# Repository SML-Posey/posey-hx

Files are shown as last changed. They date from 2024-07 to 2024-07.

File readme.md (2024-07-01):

# Posey Hub Platform

This is a simple IMU hardware platform sized to fit in a waist-mounted device. The hub unit operates as both an IMU and a data collection device, connecting to other Posey devices and logging their data to on-board flash.

It includes:

- nRF5340 ARM microtroller with BLE radio
- CEVA BNO086 9-axis IMU
- Flash
- Lithium-polymer operation and charging

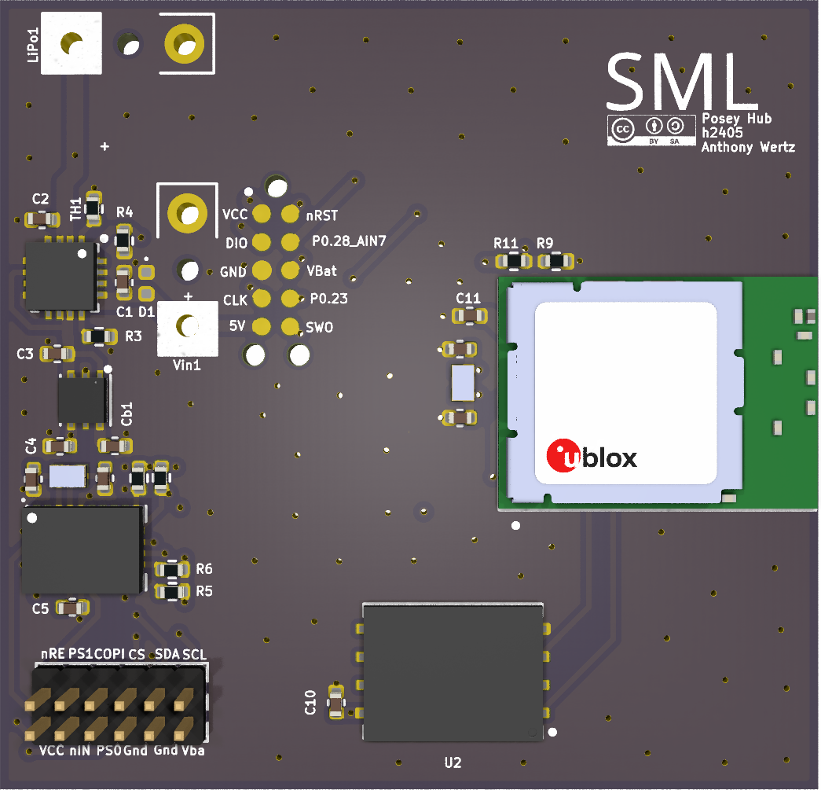
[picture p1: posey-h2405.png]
CAD rendering


## Author

[Anthony Wertz](https://me.anthonywertz.com)

## License

Shield: [][cc-by-sa]

This work is licensed under a
[Creative Commons Attribution-ShareAlike 4.0 International License][cc-by-sa].

[][cc-by-sa]

[cc-by-sa]: http://creativecommons.org/licenses/by-sa/4.0/
[cc-by-sa-image]: https://licensebuttons.net/l/by-sa/4.0/88x31.png
[cc-by-sa-shield]: https://img.shields.io/badge/License-CC%20BY--SA%204.0-lightgrey.svg

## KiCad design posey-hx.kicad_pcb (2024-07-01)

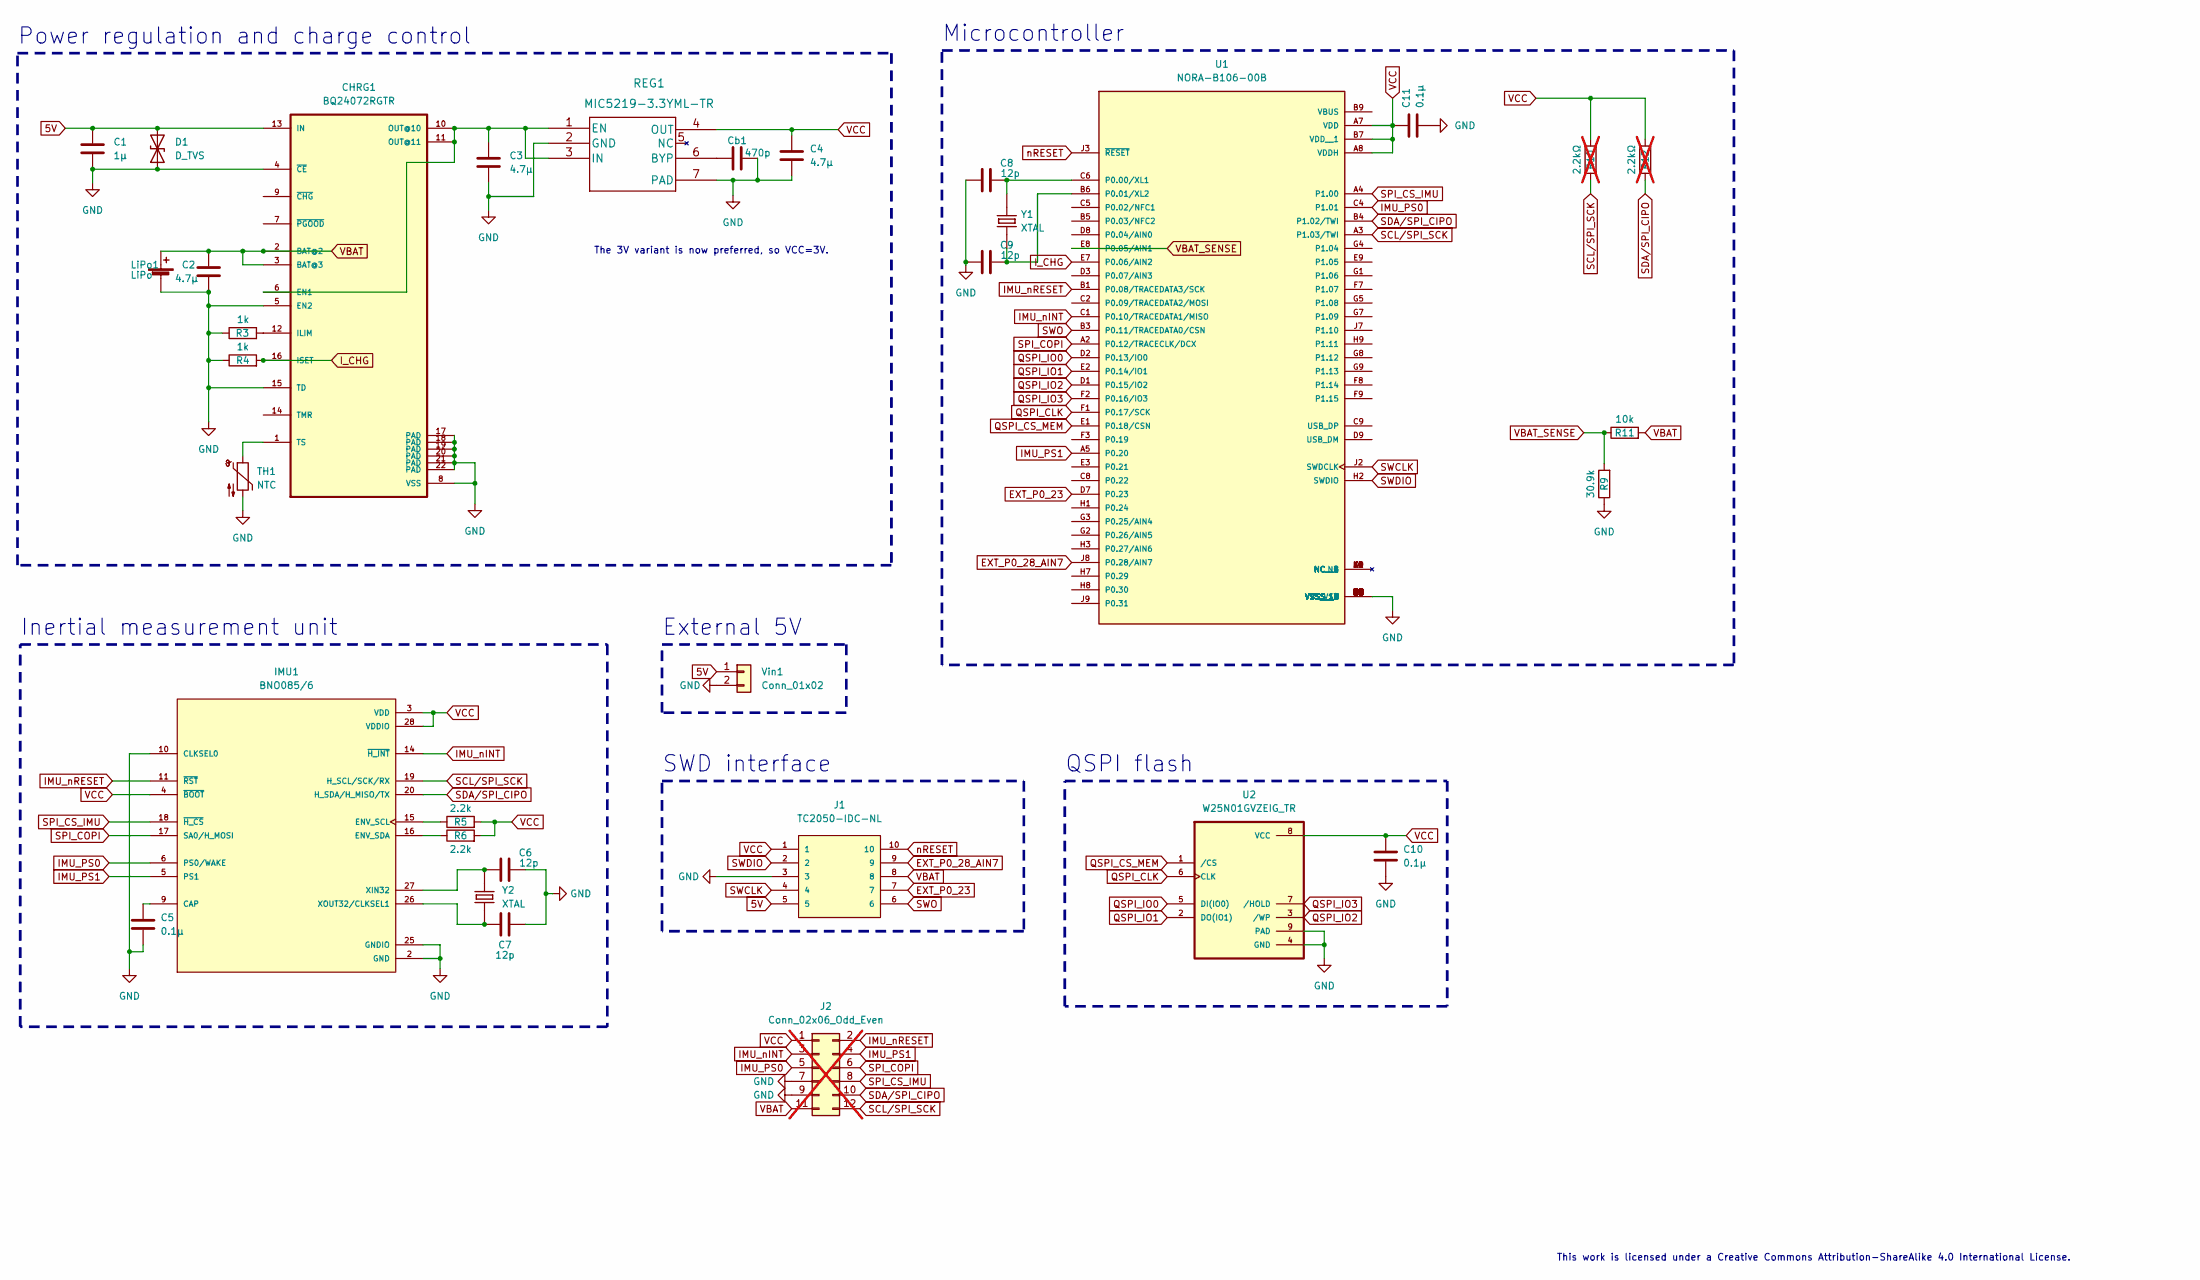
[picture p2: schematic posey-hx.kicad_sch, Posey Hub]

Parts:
C1: 1µ; C_0402_1005Metric
C2, C3, C4: 4.7µ; C_0402_1005Metric
C5, C10, C11: 0.1µ; C_0402_1005Metric
C6, C7, C8, C9: 12p; C_0402_1005Metric
CHRG1: BQ24072RGTR; QFN50P300X300X100-17N
Cb1: 470p; C_0402_1005Metric
D1: D_TVS; D_0402_1005Metric
IMU1: BNO085/6; IC_BNO080
J1: TC2050-IDC-NL
J2: Conn_02x06_Odd_Even; PinHeader_2x06_P1.27mm_Vertical; not fitted
LiPo1: LiPo; Split Terminal 2.54
R3, R4: 1k; R_0402_1005Metric
R5, R6: 2.2k; R_0402_1005Metric
R9: 30.9k; R_0402_1005Metric
R10, R12: 2.2kΩ; R_0402_1005Metric; not fitted
R11: 10k; R_0402_1005Metric
REG1: MIC5219-3.3YML-TR
TH1: NTC; R_0402_1005Metric
U1: NORA-B106-00B; XCVR_NORA-B106-00B
U2: W25N01GVZEIG_TR; SON127P800X600X80-9N
Vin1: Conn_01x02; Split Terminal 2.54
Y1, Y2: XTAL; XTAL_ECS-.327-9-16-TR

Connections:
5V: C1.1, CHRG1.13 (IN), D1.2 (A2), J1.5, Vin1.1
EXT_P0_23: J1.7, U1.D7 (P0.23)
EXT_P0_28_AIN7: J1.9, U1.J8 (P0.28/AIN7)
GND: C1.2, C2.1, C3.2, C4.2, C5.2, C6.2, C7.2, C8.1, C9.1, C10.2, C11.2, CHRG1.4 (~CE), CHRG1.5 (EN2), CHRG1.8 (VSS), CHRG1.15 (TD), CHRG1.17 (PAD), CHRG1.18 (PAD), CHRG1.19 (PAD), CHRG1.20 (PAD), CHRG1.21 (PAD), CHRG1.22 (PAD), Cb1.2, D1.1 (A1), IMU1.2 (GND), IMU1.10 (CLKSEL0), IMU1.25 (GNDIO), J1.3, J2.7, J2.9, LiPo1.2 (-), R3.1, R4.1, R9.1, REG1.2 (GND), REG1.7 (PAD), TH1.2, U1.A1 (VSS), U1.A9 (VSS__1), U1.B2 (VSS__2), U1.B8 (VSS__3), U1.E4 (VSS__4), U1.E5 (VSS__5), U1.F4 (VSS__6), U1.F5 (VSS__7), U1.K2 (VSS__8), U1.K3 (VSS__9), U1.K5 (VSS__10), U1.K7 (VSS__11), U1.K8 (VSS__12), U1.L1 (VSS__13), U1.L9 (VSS__14), U1.M1 (VSS__15), U1.M2 (VSS__16), U1.M8 (VSS__17), U1.M9 (VSS__18), U2.4 (GND), U2.9 (PAD), Vin1.2
IMU_PS0: IMU1.6 (PS0/WAKE), J2.5, U1.C4 (P1.01)
IMU_PS1: IMU1.5 (PS1), J2.4, U1.A5 (P0.20)
IMU_nINT: IMU1.14 (~H_INT), J2.3, U1.C1 (P0.10/TRACEDATA1/MISO)
IMU_nRESET: IMU1.11 (~RST), J2.2, U1.B1 (P0.08/TRACEDATA3/SCK)
I_CHG: CHRG1.16 (ISET), R4.2, U1.E7 (P0.06/AIN2)
unnamed: C3.1, CHRG1.6 (EN1), CHRG1.10 (OUT@10), CHRG1.11 (OUT@11), REG1.1 (EN), REG1.3 (IN)
unnamed: CHRG1.12 (ILIM), R3.2
unnamed: CHRG1.1 (TS), TH1.1
unnamed: C5.1, IMU1.9 (CAP)
unnamed: IMU1.15 (ENV_SCL), R5.1
unnamed: IMU1.16 (ENV_SDA), R6.1
unnamed: C6.1, IMU1.27 (XIN32), Y2.2
unnamed: C7.1, IMU1.26 (XOUT32/CLKSEL1), Y2.1
unnamed: Cb1.1, REG1.6 (BYP)
unnamed: C8.2, U1.C6 (P0.00/XL1), Y1.1
unnamed: C9.2, U1.B6 (P0.01/XL2), Y1.2
QSPI_CLK: U1.F1 (P0.17/SCK), U2.6 (CLK)
QSPI_CS_MEM: U1.E1 (P0.18/CSN), U2.1 (/CS)
QSPI_IO0: U1.D2 (P0.13/IO0), U2.5 (DI(IO0))
QSPI_IO1: U1.E2 (P0.14/IO1), U2.2 (DO(IO1))
QSPI_IO2: U1.D1 (P0.15/IO2), U2.3 (/WP)
QSPI_IO3: U1.F2 (P0.16/IO3), U2.7 (/HOLD)
SCL/SPI_SCK: IMU1.19 (H_SCL/SCK/RX), J2.12, R10.1, U1.A3 (P1.03/TWI)
SDA/SPI_CIPO: IMU1.20 (H_SDA/H_MISO/TX), J2.10, R12.1, U1.B4 (P1.02/TWI)
SPI_COPI: IMU1.17 (SA0/H_MOSI), J2.6, U1.A2 (P0.12/TRACECLK/DCX)
SPI_CS_IMU: IMU1.18 (~H_CS), J2.8, U1.A4 (P1.00)
SWCLK: J1.4, U1.J2 (SWDCLK)
SWDIO: J1.2, U1.H2 (SWDIO)
SWO: J1.6, U1.B3 (P0.11/TRACEDATA0/CSN)
VBAT: C2.2, CHRG1.2 (BAT@2), CHRG1.3 (BAT@3), J1.8, J2.11, LiPo1.1 (+), R11.2
VBAT_SENSE: R9.2, R11.1, U1.E8 (P0.05/AIN1)
VCC: C4.1, C10.1, C11.1, IMU1.3 (VDD), IMU1.4 (~BOOT), IMU1.28 (VDDIO), J1.1, J2.1, R5.2, R6.2, R10.2, R12.2, REG1.4 (OUT), U1.A7 (VDD), U1.A8 (VDDH), U1.B7 (VDD__1), U2.8 (VCC)
nRESET: J1.10, U1.J3 (~RESET)

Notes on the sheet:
Power regulation and charge control
Microcontroller
External 5V
The 3V variant is now preferred, so VCC=3V.
Inertial measurement unit
This work is licensed under a Creative Commons Attribution-ShareAlike 4.0 International License.
SWD interface
QSPI flash

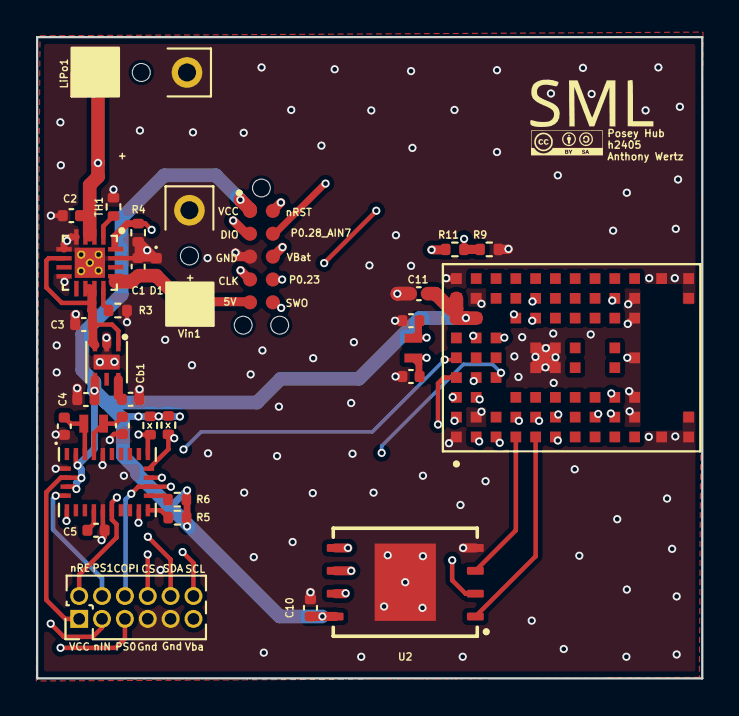
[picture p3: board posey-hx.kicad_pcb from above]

Board: 4 copper layers, 37.0 x 35.6 mm, 33 parts (0 on the bottom side), 37 nets.
